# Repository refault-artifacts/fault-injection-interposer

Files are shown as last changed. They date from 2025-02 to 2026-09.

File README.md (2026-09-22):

# Interposer PCB for DDR5 UDIMMs
Hardware files for the fault injection interposer of
REFault: A Fault Injection Platform for Rowhammer Research on DDR5 Memory.

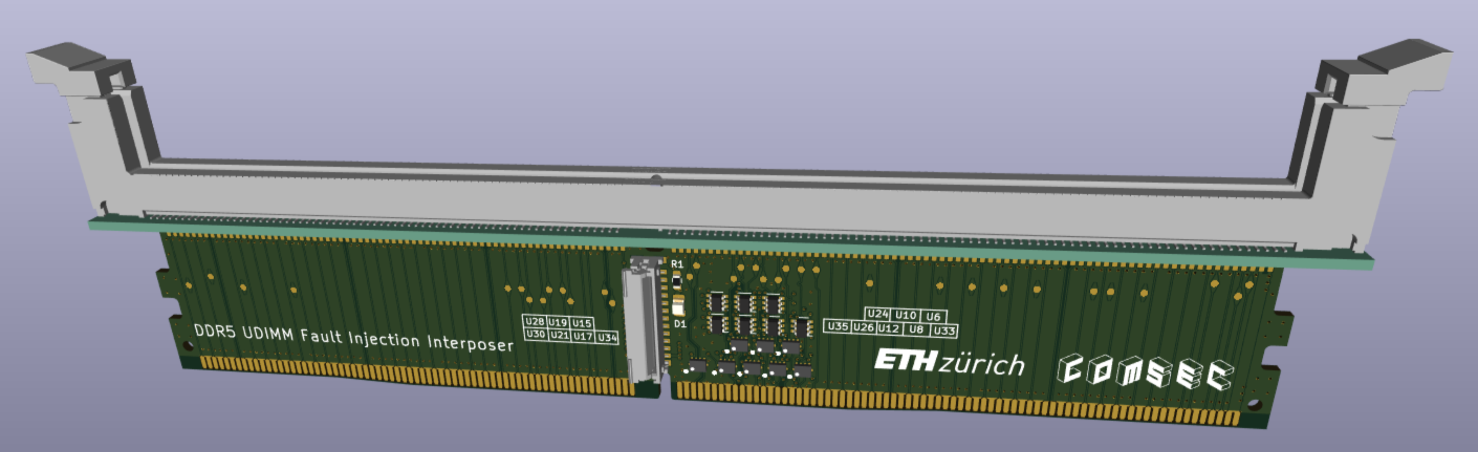
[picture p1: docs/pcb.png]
3D Rendering of PCB


The interposer consists of a 6-layer PCB that can be used in between an off-the-shelf
DDR5-compatible motherboard and an DDR5 SDRAM UDIMM. Some signals
can be forced high or low by an external control signal to inject
or suppress certain DRAM commands.

## Design
The schematic and PCB was designed in KiCAD. Open `hardware/udimm_interposer.kicad_pro` in KiCAD 8 or later to view the design files.
From there, you should be able to select the schematic and PCB layout.

For convenience, you can also find a PDF version of the schematic in `docs/schematic.pdf`. A bill of materials (BOM) is also provided in `docs`.

## Manufacturing
The PCBs were manufactured by JLCPCB and were assembled by hand.
It is reasonable to also order an SMT stencil, so soldering is easier.
The Gerber files needed for manufacturing are located at `hardware/output`.

### Impedance Control
The PCB is impedance controlled. It uses the JLC06121H-1080 stackup options.

### Manufacturing options
| Option | Value |
|---|---|
|Base Material| FR-4|
|Layers| 6|
|Dimension| 133.4 mm * 21.9 mm|
|Product Type| Industrial/Consumer electronics|
|Different Design| 1|
|Delivery Format| Single PCB|
|PCB Thickness| 1.2|
|Impedance Control| yes JLC06121H-1080|
|Layer Sequence||
|PCB Color| Green|
|Silkscreen| White|
|Via Covering| Tented|
|Surface Finish| ENIG|
|Deburring/Edge rounding| No|
|Outer Copper Weight| 1|
|Inner Copper Weight| 0.5|
|Gold Fingers| Yes|
|Flying Probe Test|Fully Test|
|Castellated Holes|no|
|Remove Order Number|No|
|Min hole size/diameter|0.3/0.4mm|
|4-Wire Kelvin Test|No|
|Material Type|FR4-Standard TG 135-140|
|Paper between PCBs|No|
|Appearance Quality|IPC Class 2 Standard|
|Confirm Production file|Yes|
|Silkscreen Technology|Ink-jet/Screen Printing Silkscreen|
|Package Box|With JLCPCB logo|

**Important**: For future orders, it may be a better idea to not select "Gold Fingers",
because we do not want chamfering along the edge connector. As far as
the PCB manufacturer is concerned, the edge connector consists of normal
pads. Otherwise add an explicit remark that you do not want any chamfering.

## Assembly
Assembly can be done manually using a stencil (ordered with the PCB),
some solder paste and a hot air gun. The connector on top was soldered
manually.
### Bill of Materials (BOM)
See docs/bom

### Verification
To ensure that there are no shorts between pins and all pins are properly
soldered, a continuity check should be performed prior to testing
the module more thoroughly with e.g. Memtest86+.

## Known Issuses
Since the UDIMM connector is comparatively long, the PCB might experience
thermal warping along the length of the connector, lifting the PCB away
from the connectors of the DIMM. For this reason, the connector was soldered
on manually.

### Modifications
Some switches are not connected to the flat flex connector.
To hard-wire them to the "passthrough" position, a wire must be soldered
to the appropriate pads on the voltage regulator side of the PCB.
Check the schematic and design files for details.

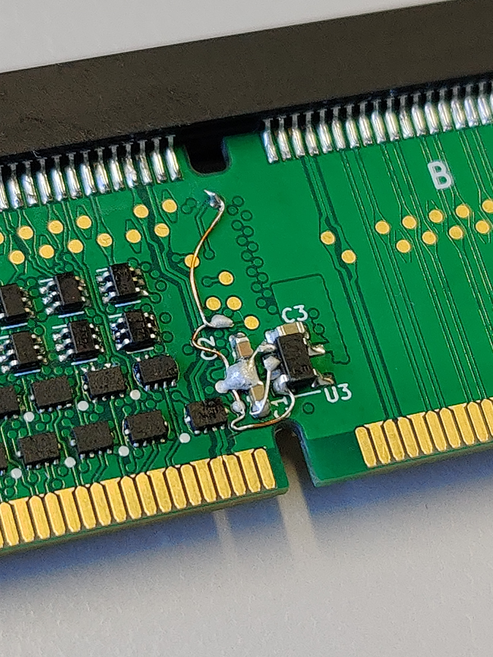
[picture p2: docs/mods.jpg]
modifications


## License
Some parts of the PCB may be subject to copyright of third parties
(e.g. 3D models provided by manufacturer).
Otherwise, the design is released under MIT License.

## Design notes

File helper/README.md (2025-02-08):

## Helper Scripts
The helper scripts are taken from 
[Microsoft/mfit](https://github.com/microsoft/mfit). They are used to take 
the DDR5 UDIMM pinout from a text file (DIMM-DDR5-288pins.txt) that was 
copied manually from the [Micron DDR5 UDIMM Core datasheet](https://media-www.micron.com/-/media/client/global/documents/products/data-sheet/modules/unbuffered_dimm/ddr5/ddr5_udimm_core.pdf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).
They allow for easy double-checking of the pinout and, most importantly,
automation of the process of creating schematic symbols in KiCad.

It is to note that the scripts generate the files in a legacy format that 
is not standard anymore with new versions of KiCad (Version 6). It is a 
simpler line-based format, where the new version uses a lisp-style 
s-expression format. Also the stdout output of the script is not usable 
directly as a KiCad file, instead the 
following had to be added to the *.lib file:
```
EESchema-LIBRARY Version 2.3 Date: 2023-02-20
#encoding utf-8
# start
DEF DDR5 U 0 10 Y Y 1 L N
DRAW

...

ENDDRAW
ENDDEF
# to 288 done
```
to make the import work.
The documentation of the legacy format can be found [here.](https://dev-docs.kicad.org/en/file-formats/legacy-4-to-6/legacy_file_format_documentation.pdf)

At some point it might be a good idea to rewrite the scripts so they generate
proper files (in s-expression format).

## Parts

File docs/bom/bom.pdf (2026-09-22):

Sheet1

Page 1

# Bill of Materials (BOM)

Project: stgloor-udimm-interposer
Date: | 22.7.2026
No | Qty Reference | Value Footprint | Manufacturer | Manufacturer Part No. | Supplier Supplier Part No. | Comment
1 | 1 | U2 | | ddr5:90414-15011-21 | UMAX | 90414-15011-21 | LCSC | C2922443
2 | 1 | U3 | 1V1 | SOT23-5 | Texas Instruments | TLV71211 Mouser | 595-TLV71211DBVR
3 | 1 | D1 Green | LED_SMD:LED_0805_2012Metric | generic | generic | generic | generic
4 | 1 | R1 | 330 | Resistor_SMD:R_0603_1608Metric | generic | generic | generic | generic
5 | 2 | C1,C3 | 100n | Capacitor_SMD:C_0603_1608Metric | generic | generic | generic | generic
6 | 1 | J1 | ddr5:5019512430 | Molex | 501951-2430 Mouser | 538-501951-2430
7 | 1 | C2 | 2.2u | Capacitor_SMD:C_0603_1608Metric | generic | generic | generic | generic
8 | 17 | ddr5:STQFN-12LD-0.5 | Texas Instruments | TMUX136 Mouser | 595-TMUX136MRSER
9 | 15 | | | SOT-363-6 | Diodes Inc | PI5A3157CEX | Mouser | 729-PI5A3157CEX

For use with adapter board Better use compatible straddle Mount type, e.g., from LOTES

U4-U12,
U22-U27,
U33,U35
U13-U21,
U28-U32,U34

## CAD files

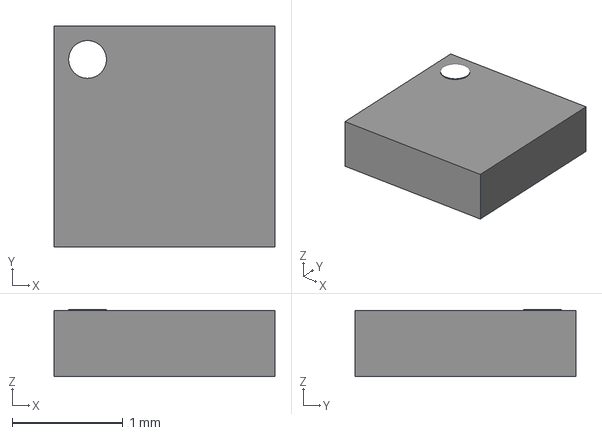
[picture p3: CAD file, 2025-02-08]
hardware/step/2x2mm_IC.step
2.00 x 2.00 x 0.61 mm

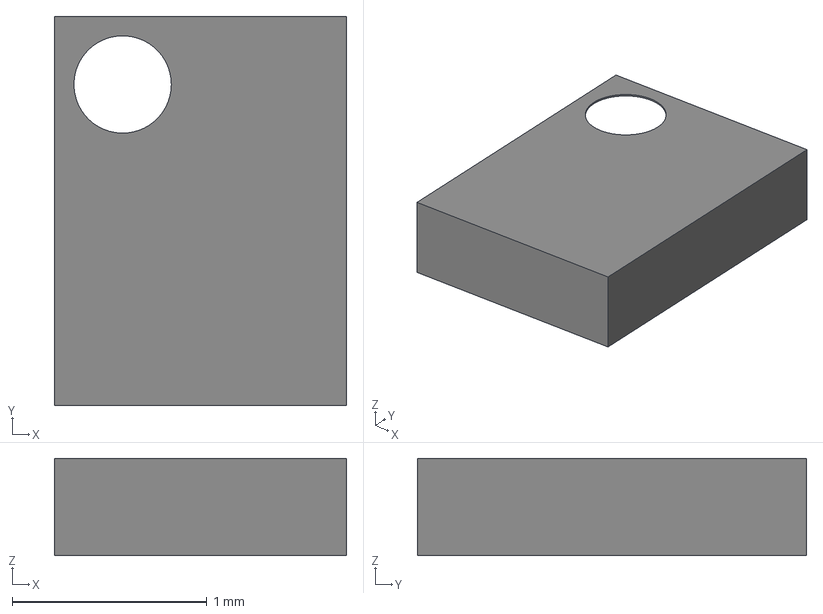
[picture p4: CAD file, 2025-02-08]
hardware/step/tmux136.step
1.50 x 2.00 x 0.5 mm

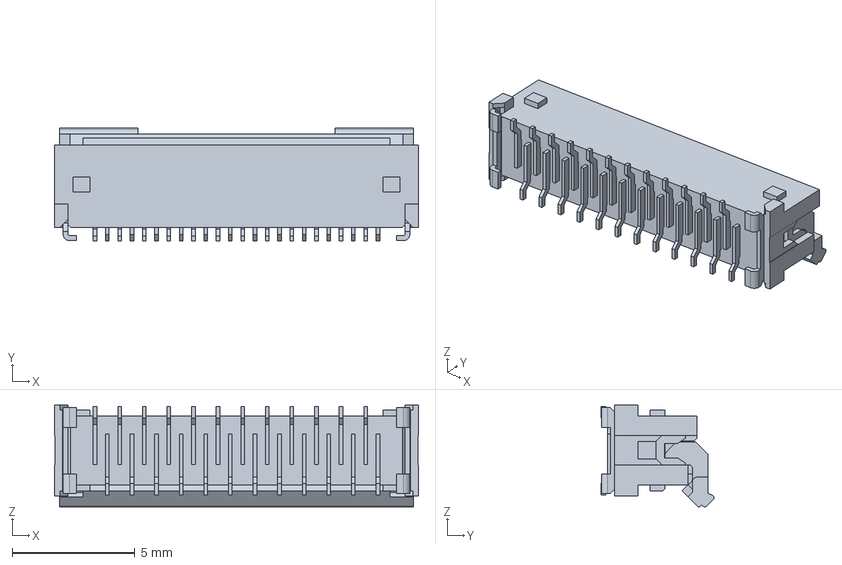
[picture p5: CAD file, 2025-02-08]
hardware/step/5019512430.stp
14.8 x 4.60 x 4.13 mm

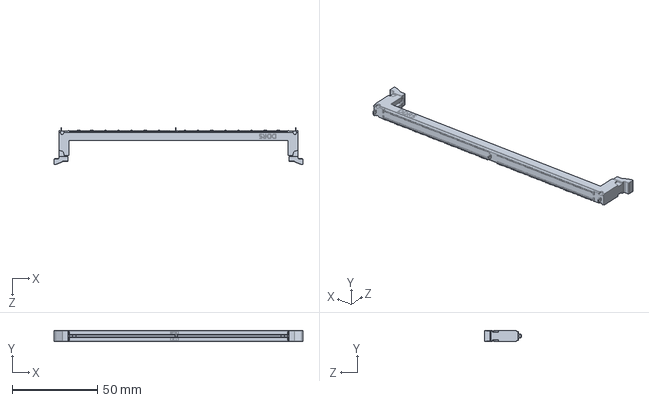
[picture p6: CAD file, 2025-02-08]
hardware/step/90414-15011-21-3d.STEP
146.4 x 6.30 x 21.9 mm

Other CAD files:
hardware/step/tmux136.FCStd

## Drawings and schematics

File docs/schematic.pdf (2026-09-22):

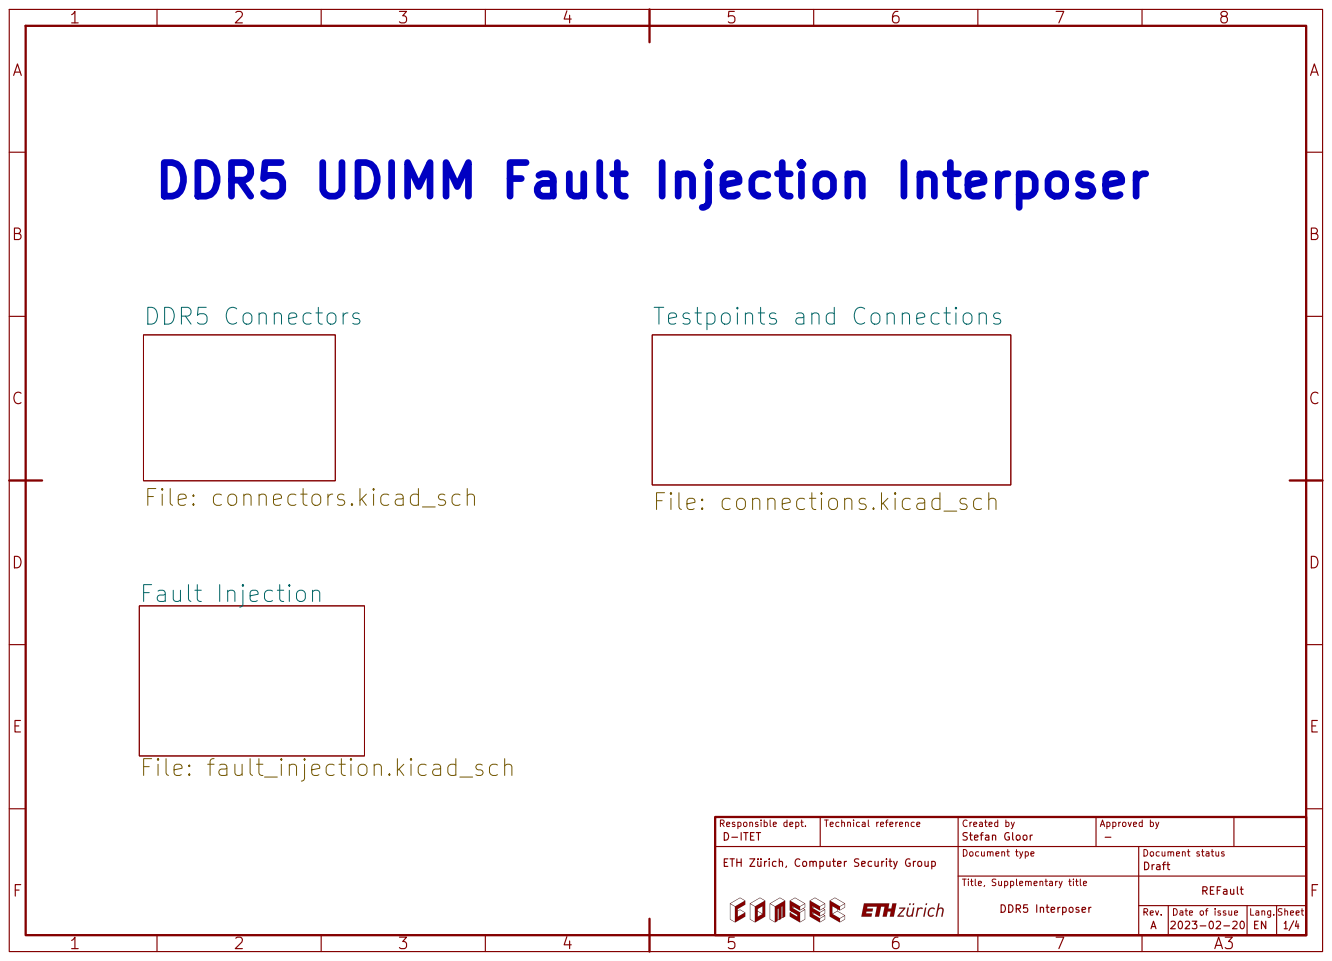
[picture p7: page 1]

DDR5 UDIMM Fault Injection Interposer

Responsible dept. D-ITET | Technical reference | Created by Stefan Gloor | Approved by -

ETH Zürich, Computer Security Group | Document type | Document status Draft

Title, Supplementary title DDR5 | REFault

Rev. A | Date of issue 2023-02-20 | Lang. Sheet Interposer EN | 1/4

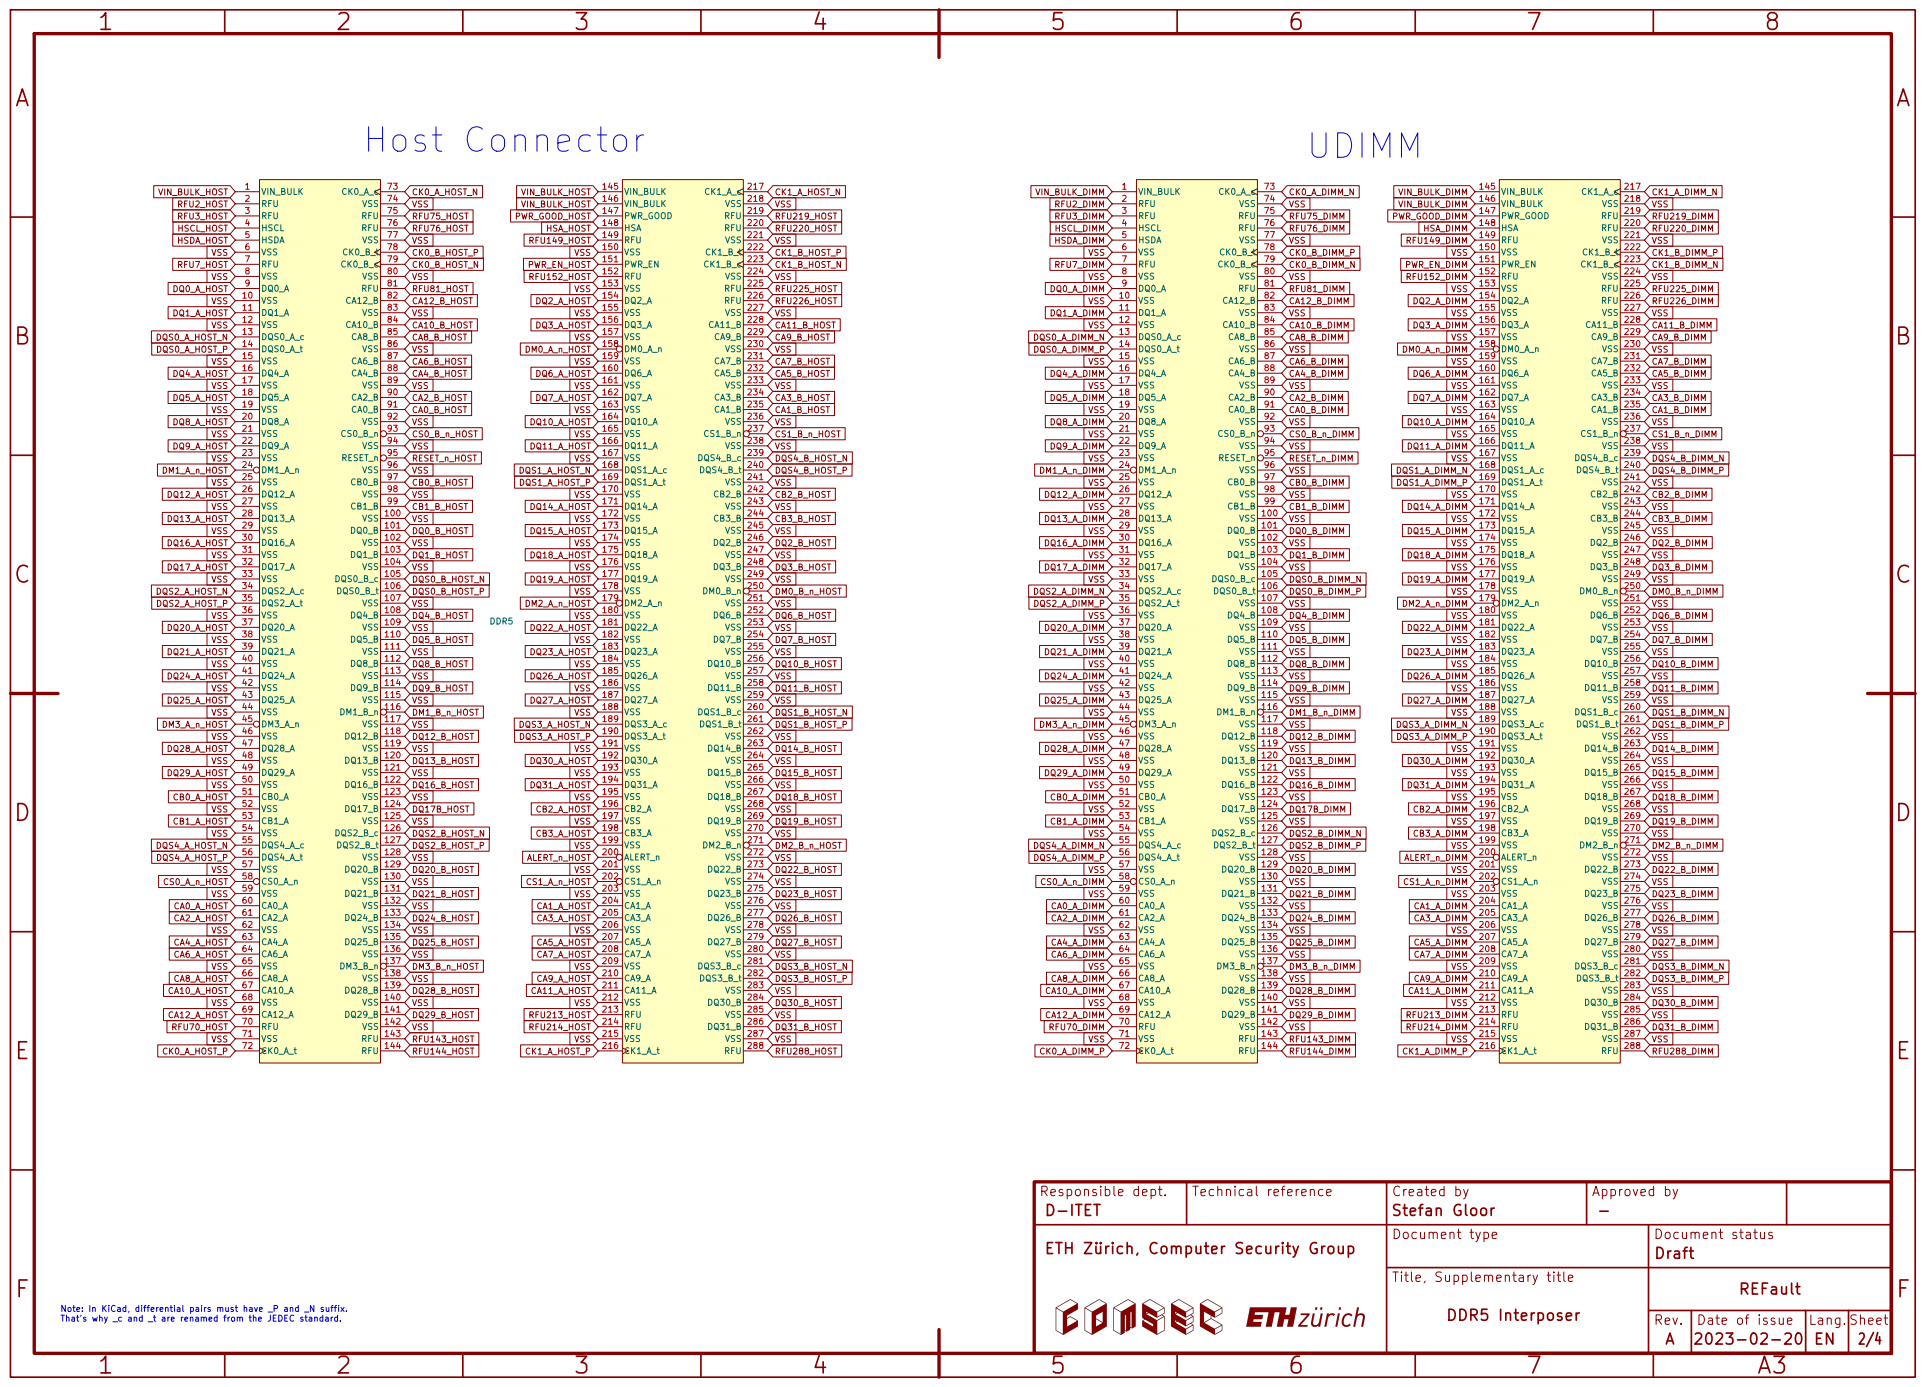
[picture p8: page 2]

Responsible dept. D-ITET | Technical reference | Created by Stefan Gloor | Approved by -

ETH Zürich, Computer Security Group | Document type | Document status Draft

Title, Supplementary title

Note: In KiCad, differential pairs must have _P and _N suffix. That's why _c and _t are renamed from the JEDEC standard.

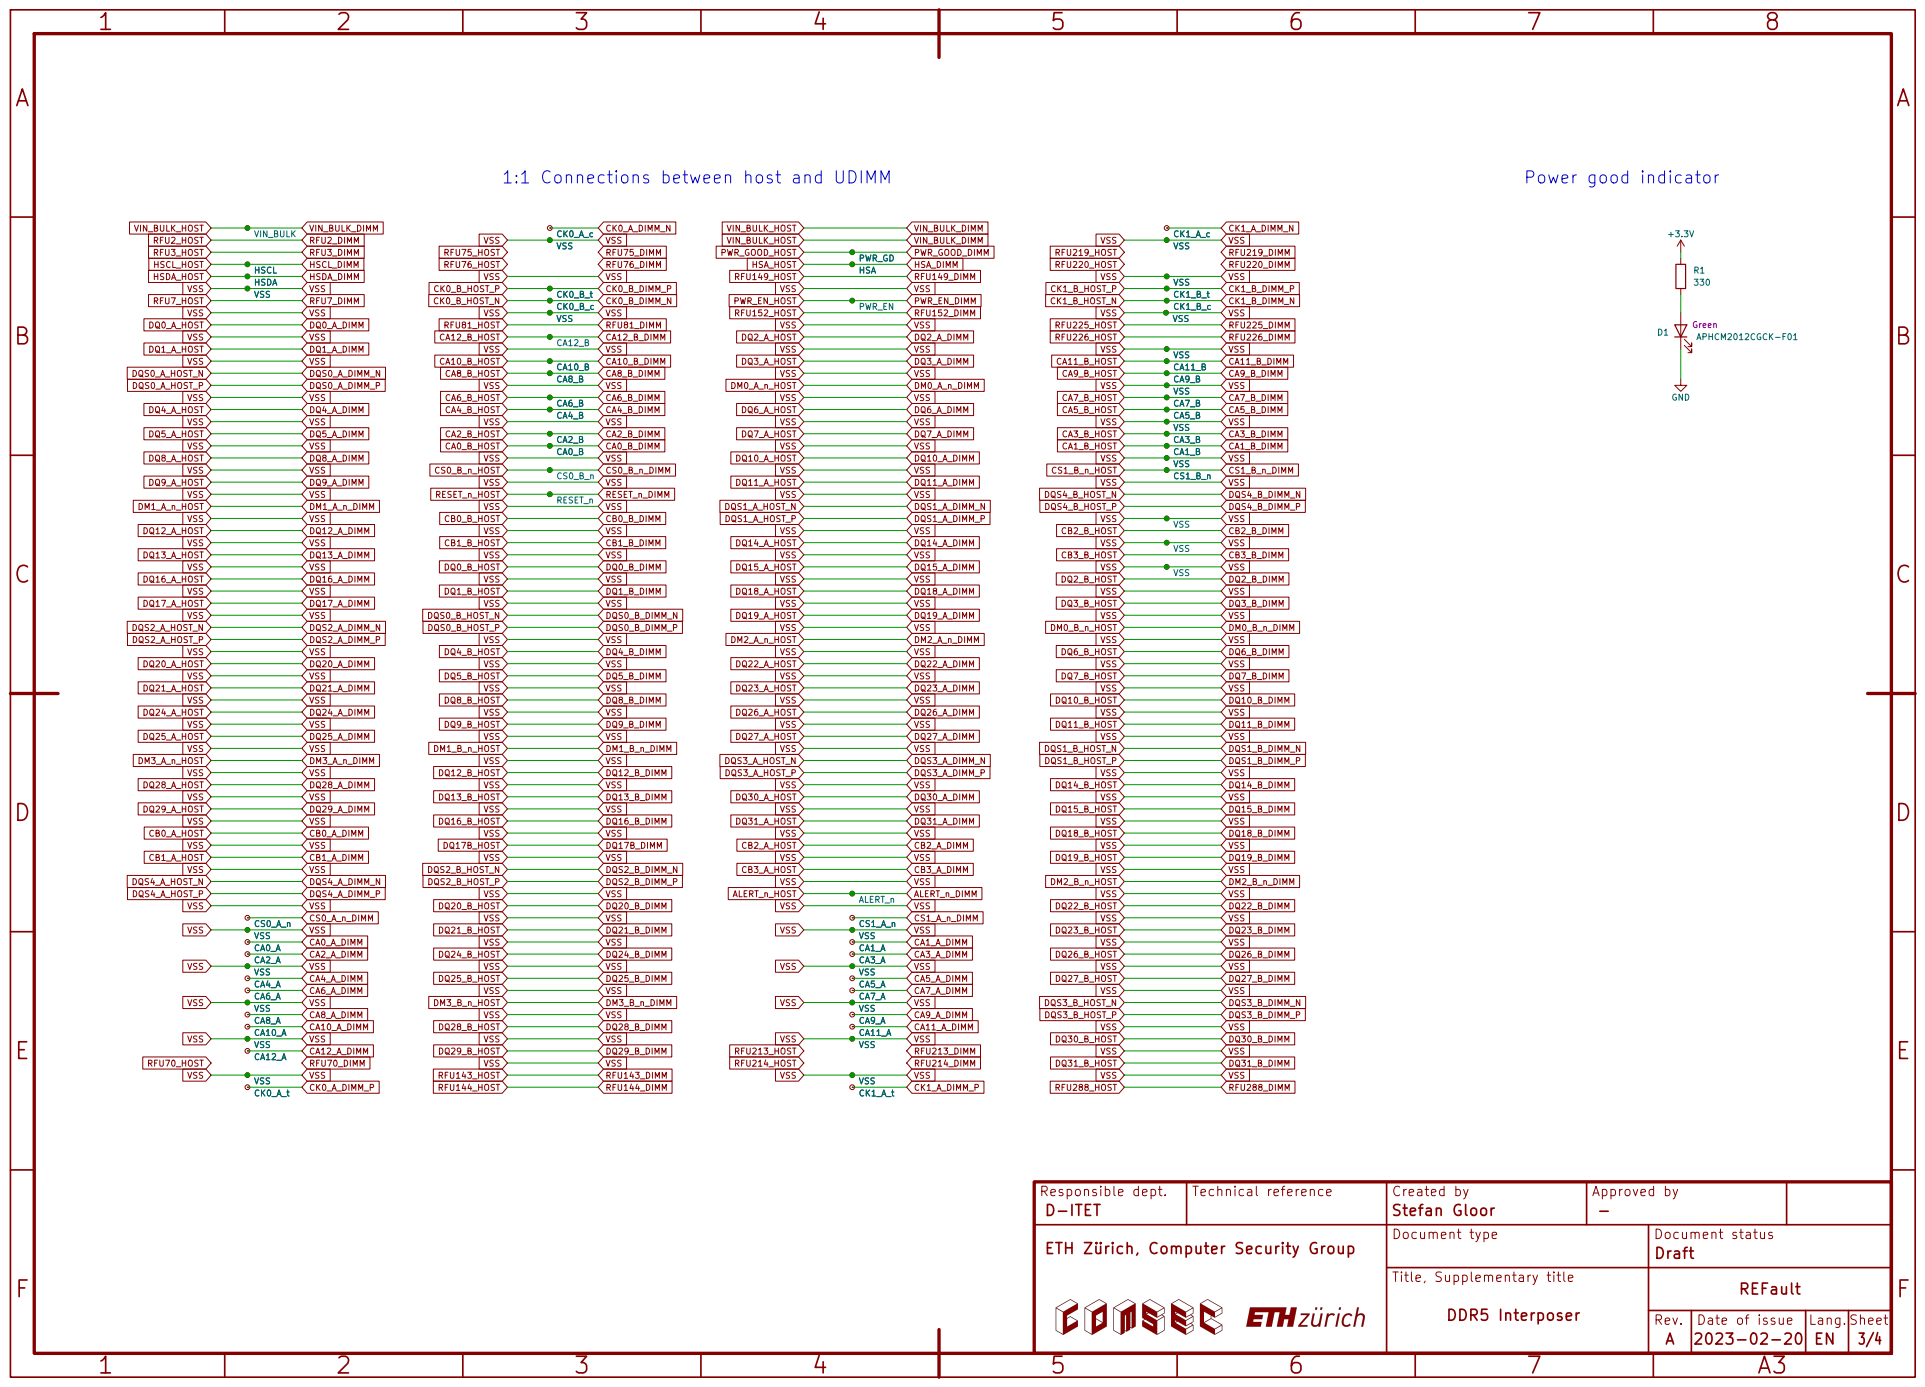
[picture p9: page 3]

Responsible dept. D-ITET | Technical reference | Created by Stefan Gloor | Approved by -

ETH Zürich, Computer Security Group | Document type | Document status Draft

Title, Supplementary title

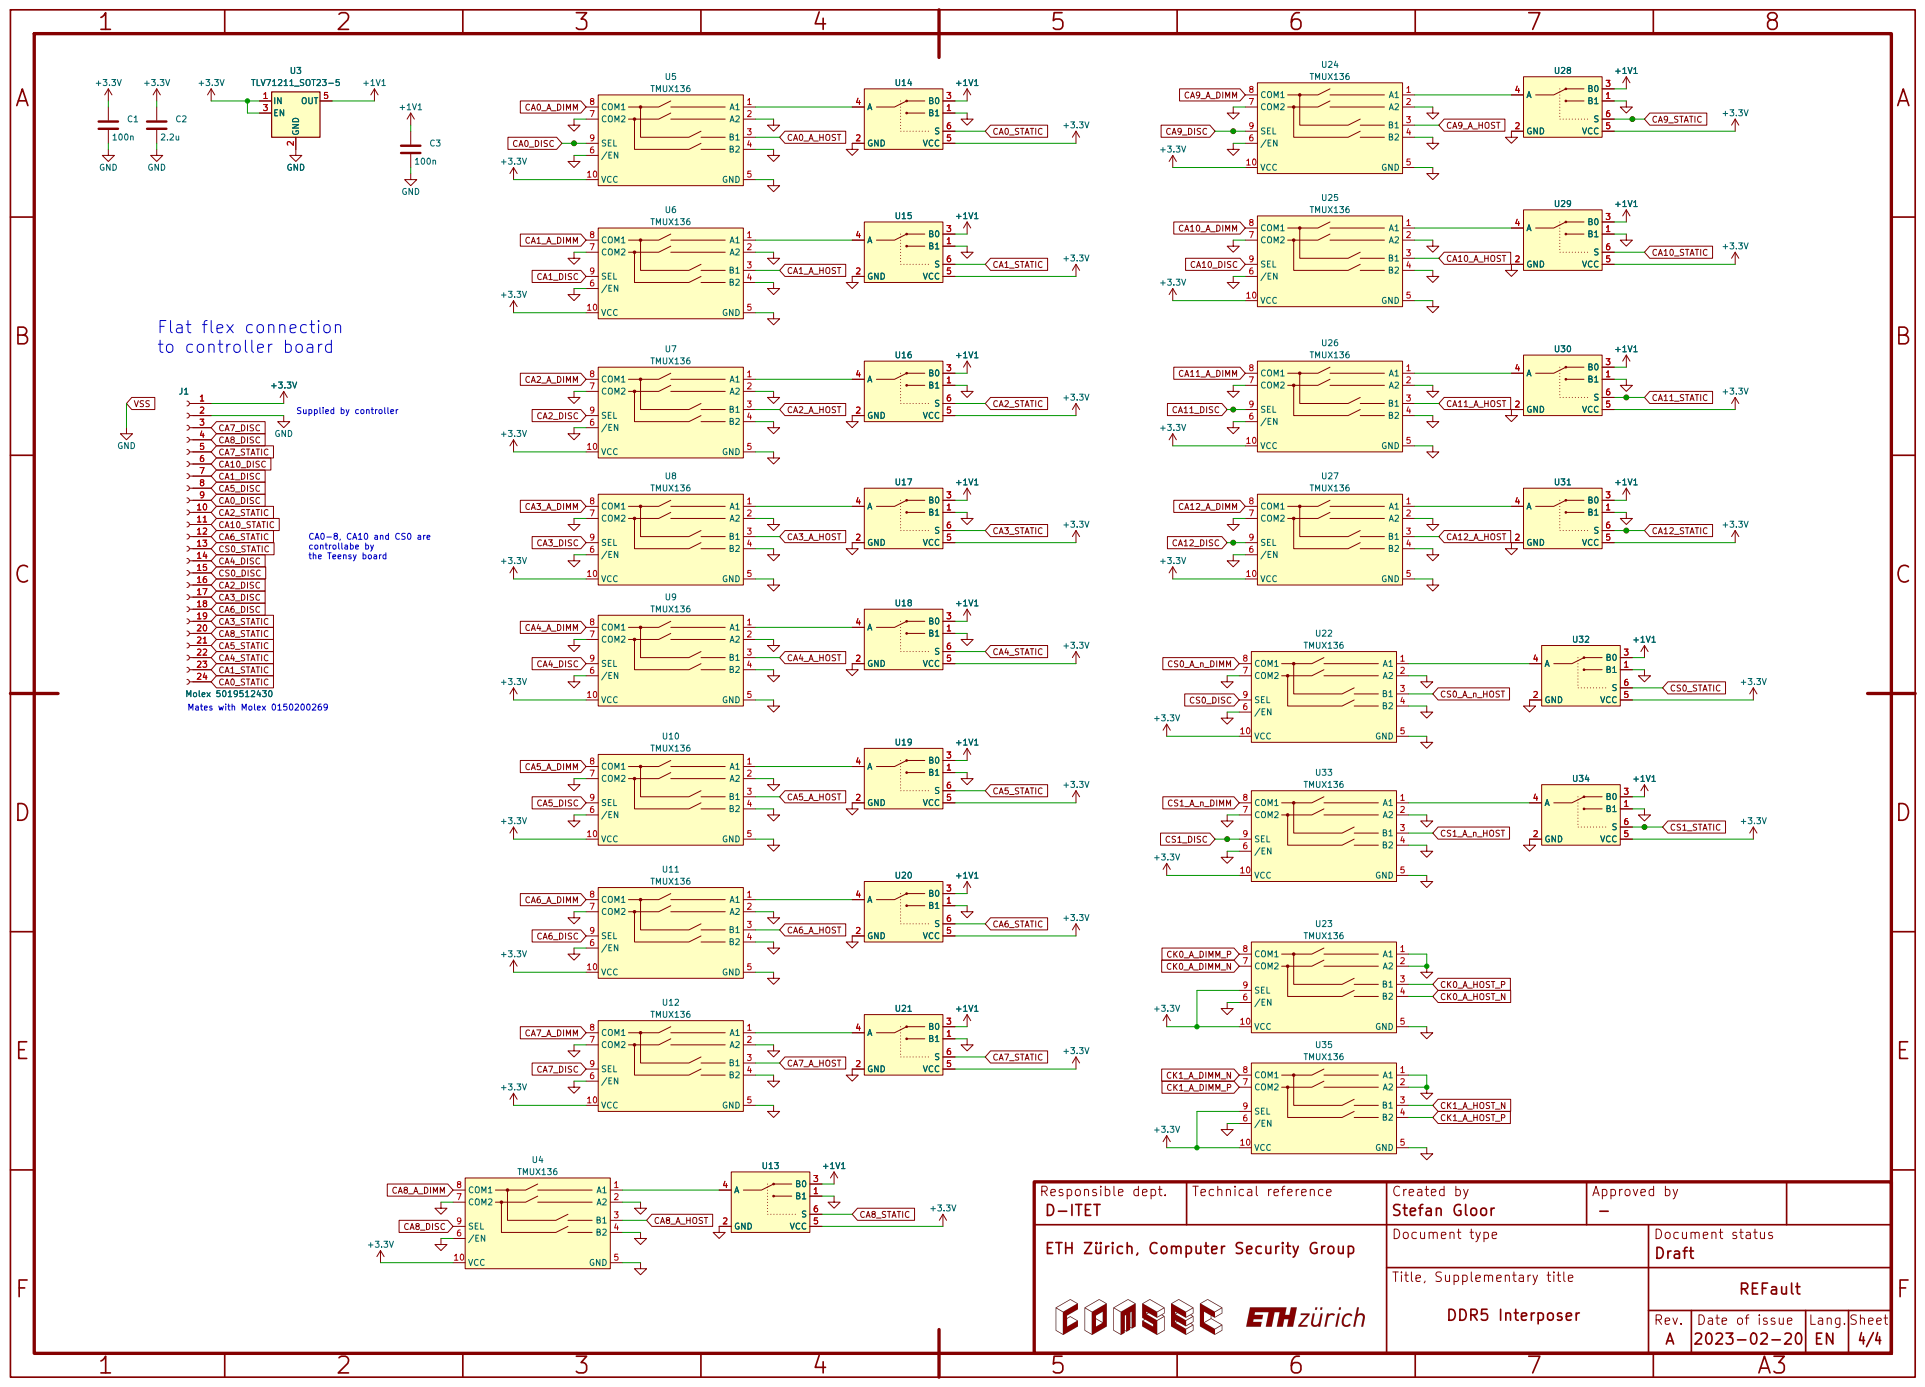
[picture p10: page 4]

Supplied by controller Flat flex connection
to controller board

CA0-8, CA10 and CS0 are controllabe by

Responsible dept. D-ITET | Technical reference | Created by Stefan Gloor | Approved by -

ETH Zürich, Computer Security Group | Document type | Document status Draft

Title, Supplementary title

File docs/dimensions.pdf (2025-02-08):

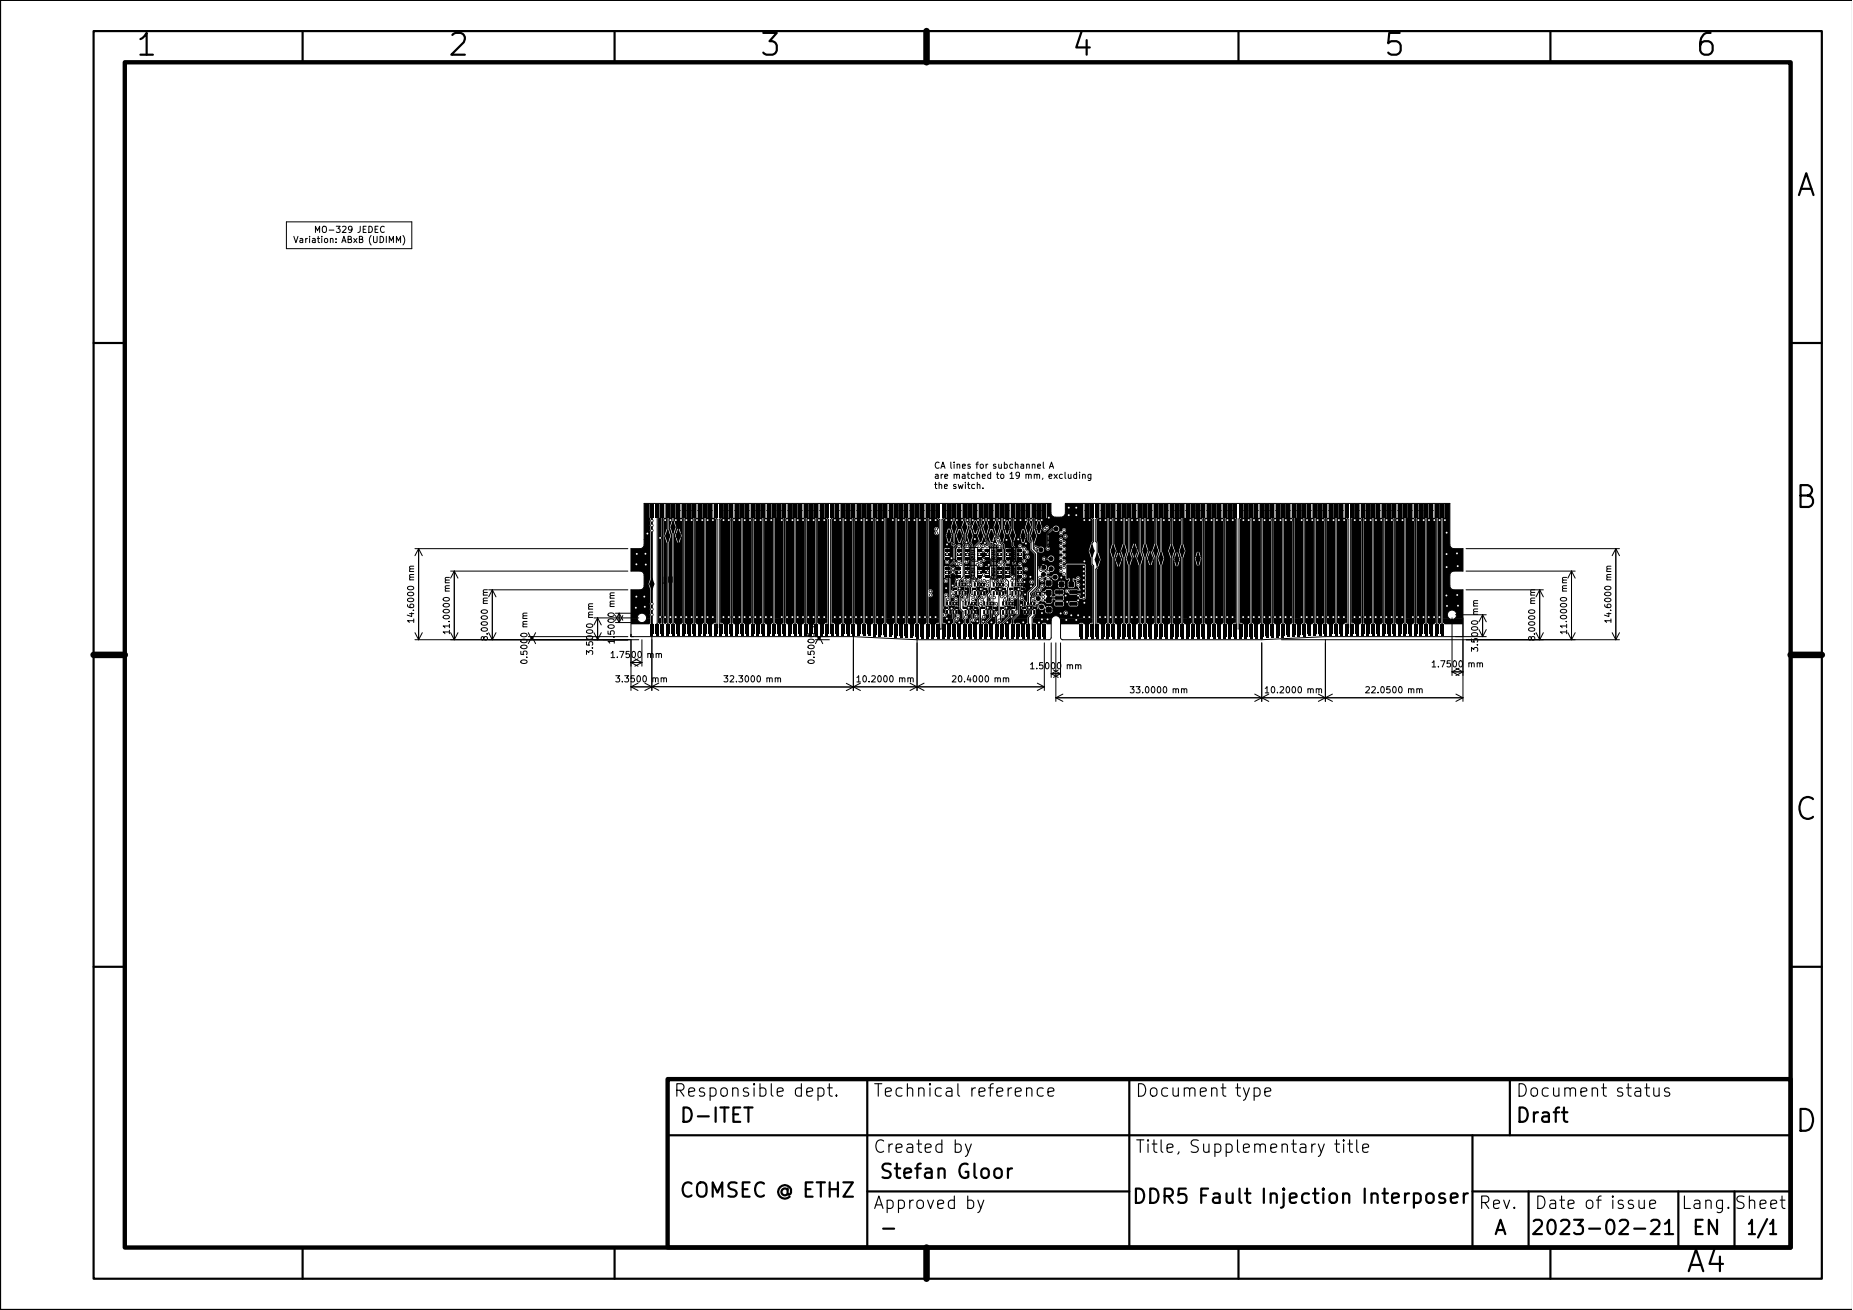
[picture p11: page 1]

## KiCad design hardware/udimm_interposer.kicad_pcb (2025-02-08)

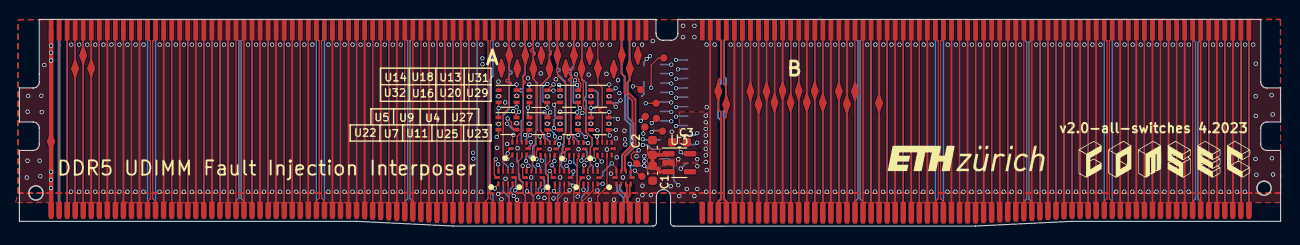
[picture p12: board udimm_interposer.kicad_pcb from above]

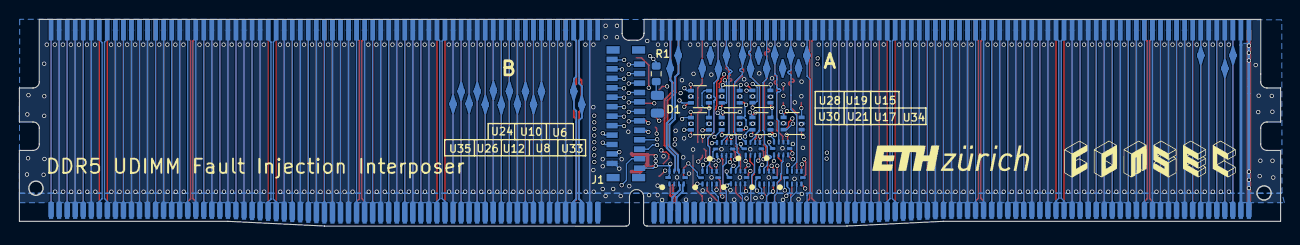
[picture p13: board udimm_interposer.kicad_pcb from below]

Board: 6 copper layers, 133.3 x 21.9 mm, 119 parts (50 on the bottom side), 225 nets.

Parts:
C1, C3: 100n; C_0603_1608Metric
C2: 2.2u; C_0603_1608Metric
D1: APHCM2012CGCK-F01; LED_0805_2012Metric
J1: Molex 5019512430; 5019512430
R1: 330; R_0603_1608Metric
TP1: VIN_BULK; testpoint
TP2: HSCL; testpoint
TP3: HSDA; testpoint
TP4, TP6, TP9, TP12, TP15, TP17, TP20, TP23, TP27, TP43, TP46, TP49, TP50, TP52, TP54, TP55, TP58, TP61, TP64, TP67, TP69, TP81, TP82: VSS; testpoint
TP5: CS0_A_n; testpoint
TP7: CA0_A; testpoint
TP8: CA2_A; testpoint
TP10: CA4_A; testpoint
TP11: CA6_A; testpoint
TP13: CA8_A; testpoint
TP14: CA10_A; testpoint
TP16: CA12_A; testpoint
TP18: CK0_A_t; testpoint
TP19: CK0_A_c; testpoint
TP21: CK0_B_t; testpoint
TP22: CK0_B_c; testpoint
TP24: CA12_B; testpoint
TP25: CA10_B; testpoint
TP26: CA8_B; testpoint
TP28: CA6_B; testpoint
TP29: CA4_B; testpoint
TP30: CA2_B; testpoint
TP31: CA0_B; testpoint
TP32: CS0_B_n; testpoint
TP34: RESET_n; testpoint
TP35: PWR_GD; testpoint
TP36: HSA; testpoint
TP38: PWR_EN; testpoint
TP39: ALERT_n; testpoint
TP40: CS1_A_n; testpoint
TP41: CA1_A; testpoint
TP42: CA3_A; testpoint
TP44: CA5_A; testpoint
TP45: CA7_A; testpoint
TP47: CA9_A; testpoint
TP48: CA11_A; testpoint
TP51: CK1_A_t; testpoint
TP53: CK1_A_c; testpoint
TP56: CK1_B_t; testpoint
TP57: CK1_B_c; testpoint
TP59: CA11_B; testpoint
TP60: CA9_B; testpoint
TP62: CA7_B; testpoint
TP63: CA5_B; testpoint
TP65: CA3_B; testpoint
TP66: CA1_B; testpoint
TP68: CS1_B_n; testpoint
TP70, TP71, TP83, TP84, TP85, TP86, TP87, TP88, TP89: tp; testpoint_small
U1: DDR5; ddr5_edge_connector
U2: UMAX 90414-15011-21; ddr5_bottom_conn_double
U3: TLV71211_SOT23-5; SOT-23-5
U4, U5, U6, U7, U8, U9, U10, U11, U12, U22, U23, U24, U25, U26, U27, U33, U35: TMUX136; uqfn10
U13, U14, U15, U16, U17, U18, U19, U20, U21, U28, U29, U30, U31, U32, U34: SOT-363_SC-70-6

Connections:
+1V1: C3.1, U3.5 (OUT), U13.3 (B0), U14.3 (B0), U15.3 (B0), U16.3 (B0), U17.3 (B0), U18.3 (B0), U19.3 (B0), U20.3 (B0), U21.3 (B0), U28.3 (B0), U29.3 (B0), U30.3 (B0), U31.3 (B0), U32.3 (B0), U34.3 (B0)
+3.3V: C1.1, C2.1, J1.1, R1.1, U3.1 (IN), U3.3 (EN), U4.10 (VCC), U5.10 (VCC), U6.10 (VCC), U7.10 (VCC), U8.10 (VCC), U9.10 (VCC), U10.10 (VCC), U11.10 (VCC), U12.10 (VCC), U13.5 (VCC), U14.5 (VCC), U15.5 (VCC), U16.5 (VCC), U17.5 (VCC), U18.5 (VCC), U19.5 (VCC), U20.5 (VCC), U21.5 (VCC), U22.10 (VCC), U23.9 (SEL), U23.10 (VCC), U24.10 (VCC), U25.10 (VCC), U26.10 (VCC), U27.10 (VCC), U28.5 (VCC), U29.5 (VCC), U30.5 (VCC), U31.5 (VCC), U32.5 (VCC), U33.10 (VCC), U34.5 (VCC), U35.9 (SEL), U35.10 (VCC)
ALERT_n_DIMM: TP39.1, U1.200 (ALERT_n), U2.200 (ALERT_n)
CA0_A_DIMM: TP7.1, U2.60 (CA0_A), U5.8 (COM1)
CA0_A_HOST: U1.60 (CA0_A), U5.3 (B1)
CA0_B_DIMM: TP31.1, U1.91 (CA0_B), U2.91 (CA0_B)
CA0_DISC: J1.9, TP71.1, U5.9 (SEL)
CA0_STATIC: J1.24, U14.6 (S)
CA1_A_DIMM: TP41.1, U2.204 (CA1_A), U6.8 (COM1)
CA1_A_HOST: U1.204 (CA1_A), U6.3 (B1)
CA1_B_DIMM: TP66.1, U1.235 (CA1_B), U2.235 (CA1_B)
CA1_DISC: J1.7, U6.9 (SEL)
CA1_STATIC: J1.23, U15.6 (S)
CA2_A_DIMM: TP8.1, U2.61 (CA2_A), U7.8 (COM1)
CA2_A_HOST: U1.61 (CA2_A), U7.3 (B1)
CA2_B_DIMM: TP30.1, U1.90 (CA2_B), U2.90 (CA2_B)
CA2_DISC: J1.16, U7.9 (SEL)
CA2_STATIC: J1.10, U16.6 (S)
CA3_A_DIMM: TP42.1, U2.205 (CA3_A), U8.8 (COM1)
CA3_A_HOST: U1.205 (CA3_A), U8.3 (B1)
CA3_B_DIMM: TP65.1, U1.234 (CA3_B), U2.234 (CA3_B)
CA3_DISC: J1.17, U8.9 (SEL)
CA3_STATIC: J1.19, U17.6 (S)
CA4_A_DIMM: TP10.1, U2.63 (CA4_A), U9.8 (COM1)
CA4_A_HOST: U1.63 (CA4_A), U9.3 (B1)
CA4_B_DIMM: TP29.1, U1.88 (CA4_B), U2.88 (CA4_B)
CA4_DISC: J1.14, U9.9 (SEL)
CA4_STATIC: J1.22, U18.6 (S)
CA5_A_DIMM: TP44.1, U2.207 (CA5_A), U10.8 (COM1)
CA5_A_HOST: U1.207 (CA5_A), U10.3 (B1)
CA5_B_DIMM: TP63.1, U1.232 (CA5_B), U2.232 (CA5_B)
CA5_DISC: J1.8, U10.9 (SEL)
CA5_STATIC: J1.21, U19.6 (S)
CA6_A_DIMM: TP11.1, U2.64 (CA6_A), U11.8 (COM1)
CA6_A_HOST: U1.64 (CA6_A), U11.3 (B1)
CA6_B_DIMM: TP28.1, U1.87 (CA6_B), U2.87 (CA6_B)
CA6_DISC: J1.18, U11.9 (SEL)
CA6_STATIC: J1.12, U20.6 (S)
CA7_A_DIMM: TP45.1, U2.208 (CA7_A), U12.8 (COM1)
CA7_A_HOST: U1.208 (CA7_A), U12.3 (B1)
CA7_B_DIMM: TP62.1, U1.231 (CA7_B), U2.231 (CA7_B)
CA7_DISC: J1.3, U12.9 (SEL)
CA7_STATIC: J1.5, U21.6 (S)
CA8_A_DIMM: TP13.1, U2.66 (CA8_A), U4.8 (COM1)
CA8_A_HOST: U1.66 (CA8_A), U4.3 (B1)
CA8_B_DIMM: TP26.1, U1.85 (CA8_B), U2.85 (CA8_B)
CA8_DISC: J1.4, U4.9 (SEL)
CA8_STATIC: J1.20, U13.6 (S)
CA9_A_DIMM: TP47.1, U2.210 (CA9_A), U24.8 (COM1)
CA9_A_HOST: U1.210 (CA9_A), U24.3 (B1)
CA9_B_DIMM: TP60.1, U1.229 (CA9_B), U2.229 (CA9_B)
CA9_DISC: TP83.1, U24.9 (SEL)
CA9_STATIC: TP70.1, U28.6 (S)
CA10_A_DIMM: TP14.1, U2.67 (CA10_A), U25.8 (COM1)
CA10_A_HOST: U1.67 (CA10_A), U25.3 (B1)
CA10_B_DIMM: TP25.1, U1.84 (CA10_B), U2.84 (CA10_B)
CA10_DISC: J1.6, U25.9 (SEL)
CA10_STATIC: J1.11, U29.6 (S)
CA11_A_DIMM: TP48.1, U2.211 (CA11_A), U26.8 (COM1)
CA11_A_HOST: U1.211 (CA11_A), U26.3 (B1)
CA11_B_DIMM: TP59.1, U1.228 (CA11_B), U2.228 (CA11_B)
CA11_DISC: TP84.1, U26.9 (SEL)
CA11_STATIC: TP86.1, U30.6 (S)
CA12_A_DIMM: TP16.1, U2.69 (CA12_A), U27.8 (COM1)
CA12_A_HOST: U1.69 (CA12_A), U27.3 (B1)
CA12_B_DIMM: TP24.1, U1.82 (CA12_B), U2.82 (CA12_B)
CA12_DISC: TP85.1, U27.9 (SEL)
CA12_STATIC: TP87.1, U31.6 (S)
CB0_A_DIMM: U1.51 (CB0_A), U2.51 (CB0_A)
CB0_B_DIMM: U1.97 (CB0_B), U2.97 (CB0_B)
CB1_A_DIMM: U1.53 (CB1_A), U2.53 (CB1_A)
CB1_B_DIMM: U1.99 (CB1_B), U2.99 (CB1_B)
CB2_A_DIMM: U1.196 (CB2_A), U2.196 (CB2_A)
CB2_B_DIMM: U1.242 (CB2_B), U2.242 (CB2_B)
CB3_A_DIMM: U1.198 (CB3_A), U2.198 (CB3_A)
CB3_B_DIMM: U1.244 (CB3_B), U2.244 (CB3_B)
CK0_A_DIMM_N: TP19.1, U2.73 (CK0_A_c), U23.7 (COM2)
CK0_A_DIMM_P: TP18.1, U2.72 (CK0_A_t), U23.8 (COM1)
CK0_A_HOST_N: U1.73 (CK0_A_c), U23.4 (B2)
CK0_A_HOST_P: U1.72 (CK0_A_t), U23.3 (B1)
CK0_B_DIMM_N: TP22.1, U1.79 (CK0_B_c), U2.79 (CK0_B_c)
CK0_B_DIMM_P: TP21.1, U1.78 (CK0_B_t), U2.78 (CK0_B_t)
CK1_A_DIMM_N: TP53.1, U2.217 (CK1_A_c), U35.8 (COM1)
CK1_A_DIMM_P: TP51.1, U2.216 (CK1_A_t), U35.7 (COM2)
CK1_A_HOST_N: U1.217 (CK1_A_c), U35.3 (B1)
CK1_A_HOST_P: U1.216 (CK1_A_t), U35.4 (B2)
CK1_B_DIMM_N: TP57.1, U1.223 (CK1_B_c), U2.223 (CK1_B_c)
CK1_B_DIMM_P: TP56.1, U1.222 (CK1_B_t), U2.222 (CK1_B_t)
CS0_A_n_DIMM: TP5.1, U2.58 (CS0_A_n), U22.8 (COM1)
CS0_A_n_HOST: U1.58 (CS0_A_n), U22.3 (B1)
CS0_B_n_DIMM: TP32.1, U1.93 (CS0_B_n), U2.93 (CS0_B_n)
CS0_DISC: J1.15, U22.9 (SEL)
CS0_STATIC: J1.13, U32.6 (S)
CS1_A_n_DIMM: TP40.1, U2.202 (CS1_A_n), U33.8 (COM1)
CS1_A_n_HOST: U1.202 (CS1_A_n), U33.3 (B1)
CS1_B_n_DIMM: TP68.1, U1.237 (CS1_B_n), U2.237 (CS1_B_n)
CS1_DISC: TP88.1, U33.9 (SEL)
CS1_STATIC: TP89.1, U34.6 (S)
DM0_A_n_DIMM: U1.158 (DM0_A_n), U2.158 (DM0_A_n)
DM0_B_n_DIMM: U1.250 (DM0_B_n), U2.250 (DM0_B_n)
DM1_A_n_DIMM: U1.24 (DM1_A_n), U2.24 (DM1_A_n)
DM1_B_n_DIMM: U1.116 (DM1_B_n), U2.116 (DM1_B_n)
DM2_A_n_DIMM: U1.179 (DM2_A_n), U2.179 (DM2_A_n)
DM2_B_n_DIMM: U1.271 (DM2_B_n), U2.271 (DM2_B_n)
DM3_A_n_DIMM: U1.45 (DM3_A_n), U2.45 (DM3_A_n)
DM3_B_n_DIMM: U1.137 (DM3_B_n), U2.137 (DM3_B_n)
DQ0_A_DIMM: U1.9 (DQ0_A), U2.9 (DQ0_A)
DQ0_B_DIMM: U1.101 (DQ0_B), U2.101 (DQ0_B)
DQ1_A_DIMM: U1.11 (DQ1_A), U2.11 (DQ1_A)
DQ1_B_DIMM: U1.103 (DQ1_B), U2.103 (DQ1_B)
DQ2_A_DIMM: U1.154 (DQ2_A), U2.154 (DQ2_A)
DQ2_B_DIMM: U1.246 (DQ2_B), U2.246 (DQ2_B)
DQ3_A_DIMM: U1.156 (DQ3_A), U2.156 (DQ3_A)
DQ3_B_DIMM: U1.248 (DQ3_B), U2.248 (DQ3_B)
DQ4_A_DIMM: U1.16 (DQ4_A), U2.16 (DQ4_A)
DQ4_B_DIMM: U1.108 (DQ4_B), U2.108 (DQ4_B)
DQ5_A_DIMM: U1.18 (DQ5_A), U2.18 (DQ5_A)
DQ5_B_DIMM: U1.110 (DQ5_B), U2.110 (DQ5_B)
DQ6_A_DIMM: U1.160 (DQ6_A), U2.160 (DQ6_A)
DQ6_B_DIMM: U1.252 (DQ6_B), U2.252 (DQ6_B)
DQ7_A_DIMM: U1.162 (DQ7_A), U2.162 (DQ7_A)
DQ7_B_DIMM: U1.254 (DQ7_B), U2.254 (DQ7_B)
DQ8_A_DIMM: U1.20 (DQ8_A), U2.20 (DQ8_A)
DQ8_B_DIMM: U1.112 (DQ8_B), U2.112 (DQ8_B)
DQ9_A_DIMM: U1.22 (DQ9_A), U2.22 (DQ9_A)
DQ9_B_DIMM: U1.114 (DQ9_B), U2.114 (DQ9_B)
DQ10_A_DIMM: U1.164 (DQ10_A), U2.164 (DQ10_A)
DQ10_B_DIMM: U1.256 (DQ10_B), U2.256 (DQ10_B)
DQ11_A_DIMM: U1.166 (DQ11_A), U2.166 (DQ11_A)
DQ11_B_DIMM: U1.258 (DQ11_B), U2.258 (DQ11_B)
DQ12_A_DIMM: U1.26 (DQ12_A), U2.26 (DQ12_A)
DQ12_B_DIMM: U1.118 (DQ12_B), U2.118 (DQ12_B)
DQ13_A_DIMM: U1.28 (DQ13_A), U2.28 (DQ13_A)
DQ13_B_DIMM: U1.120 (DQ13_B), U2.120 (DQ13_B)
DQ14_A_DIMM: U1.171 (DQ14_A), U2.171 (DQ14_A)
DQ14_B_DIMM: U1.263 (DQ14_B), U2.263 (DQ14_B)
DQ15_A_DIMM: U1.173 (DQ15_A), U2.173 (DQ15_A)
DQ15_B_DIMM: U1.265 (DQ15_B), U2.265 (DQ15_B)
DQ16_A_DIMM: U1.30 (DQ16_A), U2.30 (DQ16_A)
DQ16_B_DIMM: U1.122 (DQ16_B), U2.122 (DQ16_B)
DQ17B_DIMM: U1.124 (DQ17_B), U2.124 (DQ17_B)
DQ17_A_DIMM: U1.32 (DQ17_A), U2.32 (DQ17_A)
DQ18_A_DIMM: U1.175 (DQ18_A), U2.175 (DQ18_A)
DQ18_B_DIMM: U1.267 (DQ18_B), U2.267 (DQ18_B)
DQ19_A_DIMM: U1.177 (DQ19_A), U2.177 (DQ19_A)
DQ19_B_DIMM: U1.269 (DQ19_B), U2.269 (DQ19_B)
DQ20_A_DIMM: U1.37 (DQ20_A), U2.37 (DQ20_A)
DQ20_B_DIMM: U1.129 (DQ20_B), U2.129 (DQ20_B)
DQ21_A_DIMM: U1.39 (DQ21_A), U2.39 (DQ21_A)
DQ21_B_DIMM: U1.131 (DQ21_B), U2.131 (DQ21_B)
DQ22_A_DIMM: U1.181 (DQ22_A), U2.181 (DQ22_A)
DQ22_B_DIMM: U1.273 (DQ22_B), U2.273 (DQ22_B)
DQ23_A_DIMM: U1.183 (DQ23_A), U2.183 (DQ23_A)
DQ23_B_DIMM: U1.275 (DQ23_B), U2.275 (DQ23_B)
DQ24_A_DIMM: U1.41 (DQ24_A), U2.41 (DQ24_A)
DQ24_B_DIMM: U1.133 (DQ24_B), U2.133 (DQ24_B)
DQ25_A_DIMM: U1.43 (DQ25_A), U2.43 (DQ25_A)
DQ25_B_DIMM: U1.135 (DQ25_B), U2.135 (DQ25_B)
DQ26_A_DIMM: U1.185 (DQ26_A), U2.185 (DQ26_A)
DQ26_B_DIMM: U1.277 (DQ26_B), U2.277 (DQ26_B)
DQ27_A_DIMM: U1.187 (DQ27_A), U2.187 (DQ27_A)
DQ27_B_DIMM: U1.279 (DQ27_B), U2.279 (DQ27_B)
DQ28_A_DIMM: U1.47 (DQ28_A), U2.47 (DQ28_A)
DQ28_B_DIMM: U1.139 (DQ28_B), U2.139 (DQ28_B)
DQ29_A_DIMM: U1.49 (DQ29_A), U2.49 (DQ29_A)
DQ29_B_DIMM: U1.141 (DQ29_B), U2.141 (DQ29_B)
DQ30_A_DIMM: U1.192 (DQ30_A), U2.192 (DQ30_A)
DQ30_B_DIMM: U1.284 (DQ30_B), U2.284 (DQ30_B)
DQ31_A_DIMM: U1.194 (DQ31_A), U2.194 (DQ31_A)
DQ31_B_DIMM: U1.286 (DQ31_B), U2.286 (DQ31_B)
DQS0_A_DIMM_N: U1.13 (DQS0_A_c), U2.13 (DQS0_A_c)
DQS0_A_DIMM_P: U1.14 (DQS0_A_t), U2.14 (DQS0_A_t)
DQS0_B_DIMM_N: U1.105 (DQS0_B_c), U2.105 (DQS0_B_c)
DQS0_B_DIMM_P: U1.106 (DQS0_B_t), U2.106 (DQS0_B_t)
DQS1_A_DIMM_N: U1.168 (DQS1_A_c), U2.168 (DQS1_A_c)
DQS1_A_DIMM_P: U1.169 (DQS1_A_t), U2.169 (DQS1_A_t)
DQS1_B_DIMM_N: U1.260 (DQS1_B_c), U2.260 (DQS1_B_c)
DQS1_B_DIMM_P: U1.261 (DQS1_B_t), U2.261 (DQS1_B_t)
DQS2_A_DIMM_N: U1.34 (DQS2_A_c), U2.34 (DQS2_A_c)
DQS2_A_DIMM_P: U1.35 (DQS2_A_t), U2.35 (DQS2_A_t)
DQS2_B_DIMM_N: U1.126 (DQS2_B_c), U2.126 (DQS2_B_c)
DQS2_B_DIMM_P: U1.127 (DQS2_B_t), U2.127 (DQS2_B_t)
DQS3_A_DIMM_N: U1.189 (DQS3_A_c), U2.189 (DQS3_A_c)
DQS3_A_DIMM_P: U1.190 (DQS3_A_t), U2.190 (DQS3_A_t)
DQS3_B_DIMM_N: U1.281 (DQS3_B_c), U2.281 (DQS3_B_c)
DQS3_B_DIMM_P: U1.282 (DQS3_B_t), U2.282 (DQS3_B_t)
DQS4_A_DIMM_N: U1.55 (DQS4_A_c), U2.55 (DQS4_A_c)
DQS4_A_DIMM_P: U1.56 (DQS4_A_t), U2.56 (DQS4_A_t)
DQS4_B_DIMM_N: U1.239 (DQS4_B_c), U2.239 (DQS4_B_c)
DQS4_B_DIMM_P: U1.240 (DQS4_B_t), U2.240 (DQS4_B_t)
HSA_DIMM: TP36.1, U1.148 (HSA), U2.148 (HSA)
HSCL_DIMM: TP2.1, U1.4 (HSCL), U2.4 (HSCL)
HSDA_DIMM: TP3.1, U1.5 (HSDA), U2.5 (HSDA)
unnamed: D1.2 (A), R1.2
unnamed: U10.1 (A1), U19.4 (A)
unnamed: U11.1 (A1), U20.4 (A)
unnamed: U12.1 (A1), U21.4 (A)
unnamed: U4.1 (A1), U13.4 (A)
unnamed: U5.1 (A1), U14.4 (A)
unnamed: U6.1 (A1), U15.4 (A)
unnamed: U7.1 (A1), U16.4 (A)
unnamed: U8.1 (A1), U17.4 (A)
unnamed: U9.1 (A1), U18.4 (A)
unnamed: U22.1 (A1), U32.4 (A)
unnamed: U24.1 (A1), U28.4 (A)
unnamed: U25.1 (A1), U29.4 (A)
unnamed: U26.1 (A1), U30.4 (A)
unnamed: U27.1 (A1), U31.4 (A)
unnamed: U33.1 (A1), U34.4 (A)
PWR_EN_DIMM: TP38.1, U1.151 (PWR_EN), U2.151 (PWR_EN)
PWR_GOOD_DIMM: TP35.1, U1.147 (PWR_GOOD), U2.147 (PWR_GOOD)
RESET_n_DIMM: TP34.1, U1.95 (RESET_n), U2.95 (RESET_n)
RFU2_DIMM: U1.2 (RFU), U2.2 (RFU)
RFU3_DIMM: U1.3 (RFU), U2.3 (RFU)
RFU7_DIMM: U1.7 (RFU), U2.7 (RFU)
RFU81_DIMM: U1.81 (RFU), U2.81 (RFU)
RFU143_DIMM: U1.143 (RFU), U2.143 (RFU)
RFU144_DIMM: U1.144 (RFU), U2.144 (RFU)
RFU149_DIMM: U1.149 (RFU), U2.149 (RFU)
RFU152_DIMM: U1.152 (RFU), U2.152 (RFU)
RFU225_DIMM: U1.225 (RFU), U2.225 (RFU)
RFU226_DIMM: U1.226 (RFU), U2.226 (RFU)
RFU288_DIMM: U1.288 (RFU), U2.288 (RFU)
VIN_BULK_DIMM: TP1.1, U1.1 (VIN_BULK), U1.145 (VIN_BULK), U1.146 (VIN_BULK), U2.1 (VIN_BULK), U2.145 (VIN_BULK), U2.146 (VIN_BULK)
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

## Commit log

2025-02-08 feat: add design files
    [2x2mm_IC.step, 5019512430.stp, 90414-15011-21-3d.STEP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]
2026-09-22 docs: make sure bom and schematics are consistent
    Update bill of material to make sure it is consistent
    with the current version of the schematics. Re-export
    schematics for good measure as well.
    [bom.xlsx]
2026-09-22 docs(readme): drop voltage regulator bodge
    The voltage regulator currently referenced
    in schematics and bom is available and
    compatible to the SOT23-5 footprint on the PCB.
    Hence, no rework is required, so drop the note
    in the readme.
